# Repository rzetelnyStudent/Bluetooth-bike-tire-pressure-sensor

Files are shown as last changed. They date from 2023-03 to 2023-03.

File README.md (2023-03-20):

# Bluetooth-bike-tire-pressure-sensor
Bluetooth tire pressure sensor project. Measures pressure, tempreture and battery percentage.  Readings could be displayed with TPMSII android app from Play Store. Sensor is designed to be integrated with a valve and to bemounted inside a bike rim. 

This project was developed around nrf52832 microcontroller with Segger Embedded Studio and Nordic Semi SDK statement v17.1.0. Softdevice v7.2.0 (Bluetooth stack) from Nordic Semi was used.

For this project a custom PCB was designed in Altium Designer and a custom housing in TinkerCAD.

Functional description:
The sensor broadcasts pressure, temperature and battery data over BLE. The data format is compatible with the one used by BLE pressure sensor from aliexpress, like these:
https://youtu.be/v4x5Eum56oU

TPMSII Android app maps sensors using an ID coded in each sensor name and advertising data. Data format used by orginal sensors is described here:
https://github.com/ra6070/BLE-TPMS

My sensor is motion activated. It advertises data as long as the motion is detected. When motion stops for longer than 2 minutes, sensor stops advertising to preserve a battery. 

The sensor is powered using two CR927 batteries. The estimated battery lifetime is 3 years minimum assuming daily usage of 15 minutes.

Photo gallery:










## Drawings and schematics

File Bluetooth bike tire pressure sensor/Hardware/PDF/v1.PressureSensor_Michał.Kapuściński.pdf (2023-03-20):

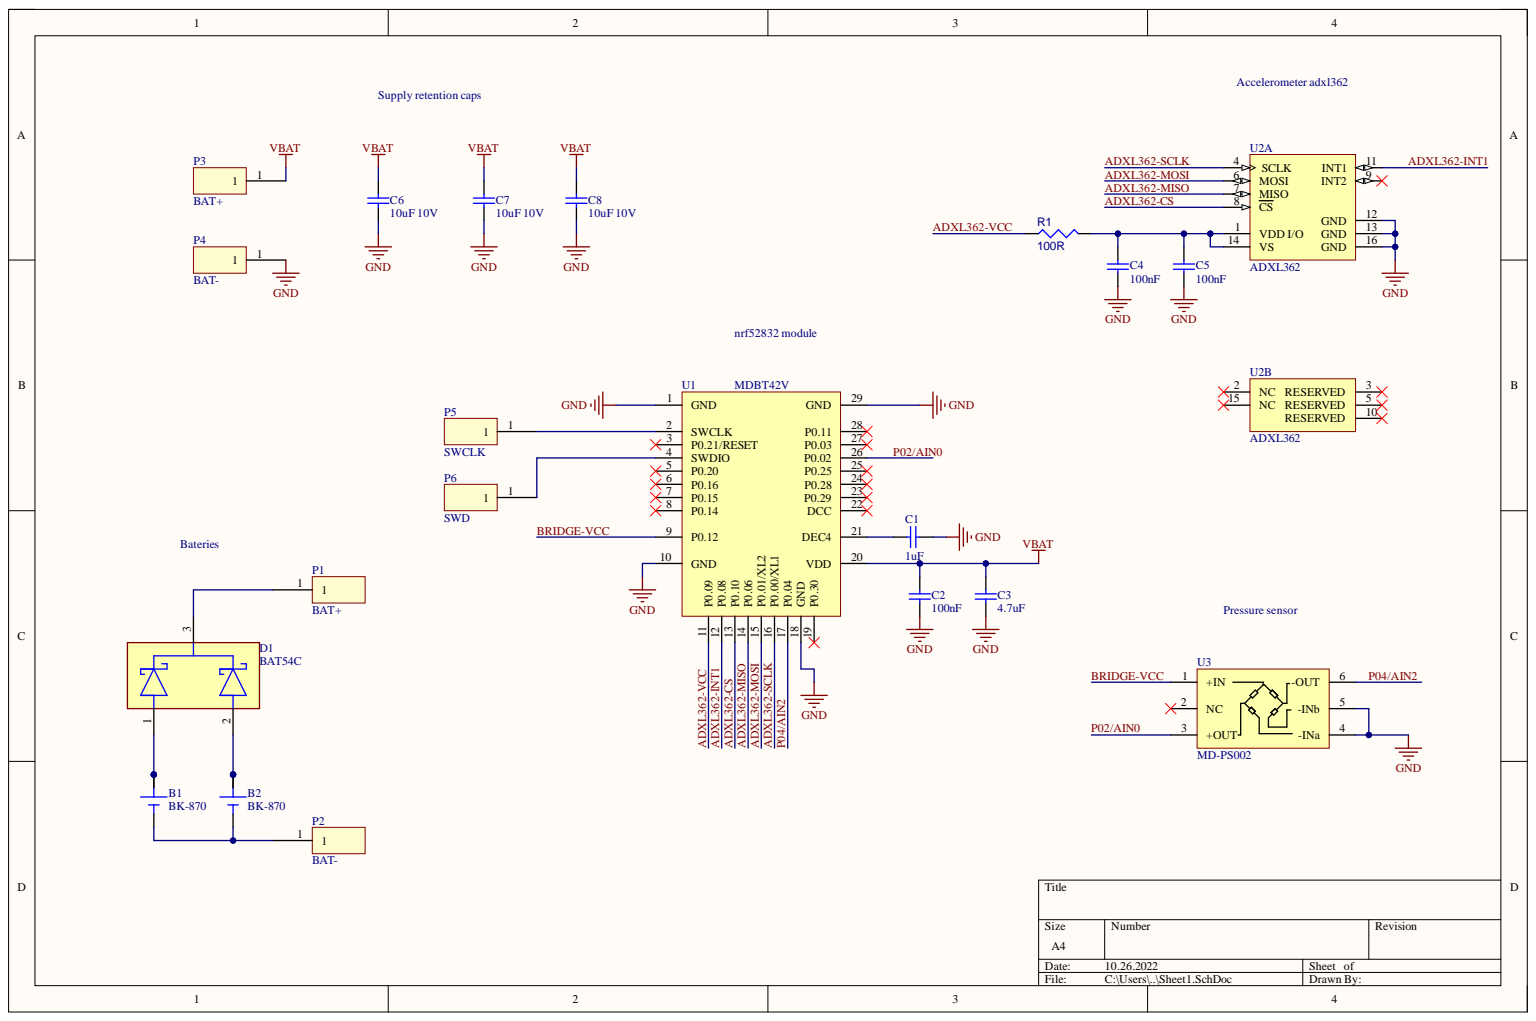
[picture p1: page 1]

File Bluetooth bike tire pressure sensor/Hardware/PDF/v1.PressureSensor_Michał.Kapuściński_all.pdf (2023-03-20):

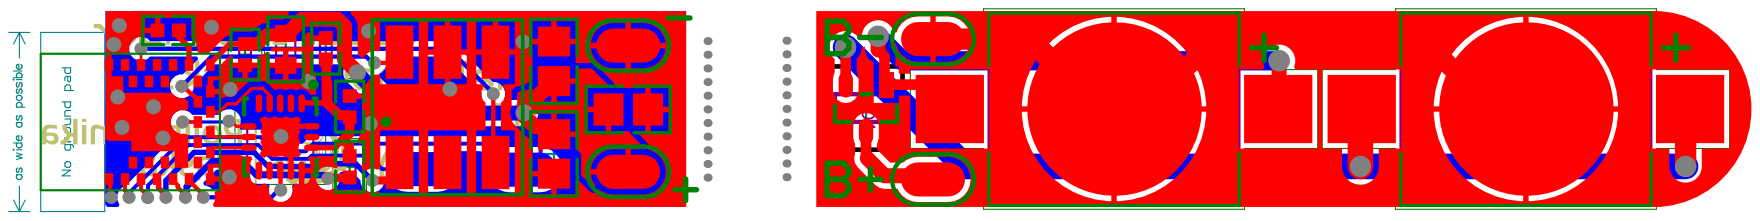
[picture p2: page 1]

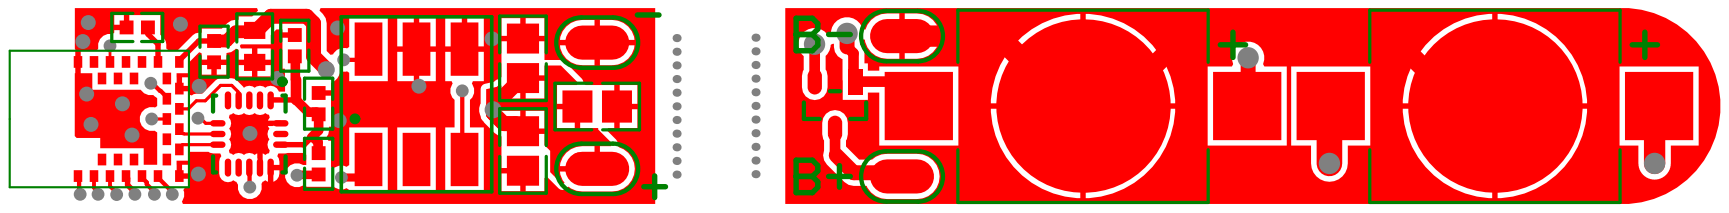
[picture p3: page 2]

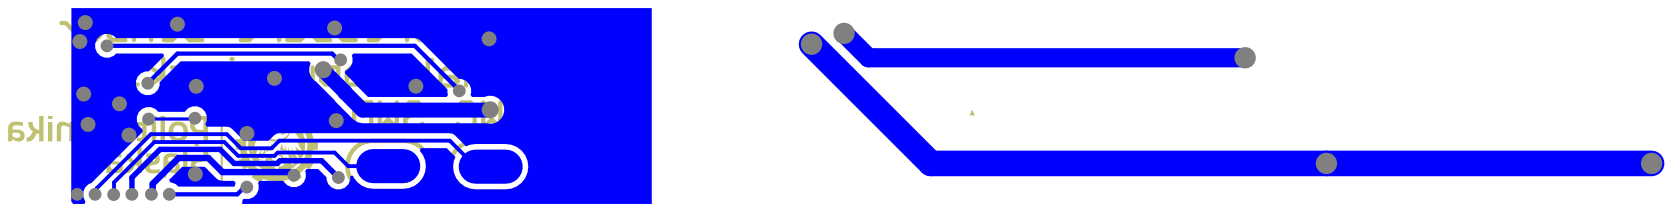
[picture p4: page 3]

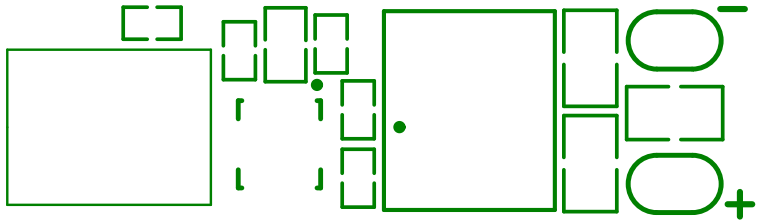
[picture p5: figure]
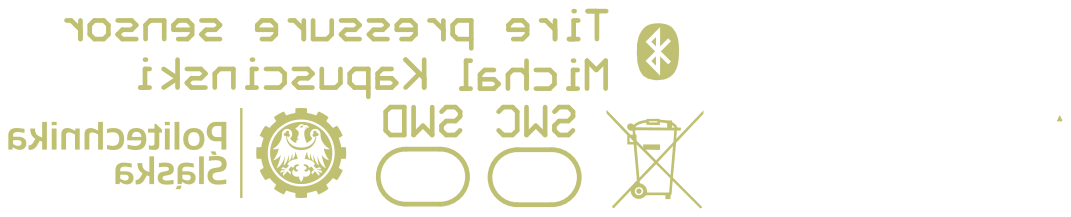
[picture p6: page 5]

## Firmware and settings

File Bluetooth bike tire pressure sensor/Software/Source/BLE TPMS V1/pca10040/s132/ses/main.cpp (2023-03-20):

/* Bluetooth tire pressure sensor project. Measures pressure, tempreture and battery percentage.
 * Readings could be displayed with TPMSII android app 
 */


#include "Sensor_id.h"
#include "Adxl362.h"
#include "my_advertising.h"
#include "my_config.h"
#include "ADC.h"
#include "mapper.h"
#include "measurments.h"
#include "sd_func_wrapper.h"



static bool timer_flag = false;
static uint8_t read_vbat_counter = 0;
APP_TIMER_DEF(m_app_timer_id);



/*
 * Main timer handler function that gets called every timer interval. I put all the application code in main().
 */
static void app_timer_handler(void *p_context)
{
    timer_flag = true;
    read_vbat_counter++;
}



/**@brief Function for starting timers.
 */
static void reading_timer_start(void)
{
    uint32_t err_code = app_timer_create(&m_app_timer_id, APP_TIMER_MODE_REPEATED, app_timer_handler); // Create timers
    APP_ERROR_CHECK(err_code);
    err_code = app_timer_start(m_app_timer_id, READ_TIMER_INTERVAL, NULL);     // start main timer
    APP_ERROR_CHECK(err_code);
}



/*
 * Function for initializing app timer library. Call in setup.
 */
static void appTimerInit(void)
{
    uint32_t err_code = app_timer_init();     // Initialize timer module
    APP_ERROR_CHECK(err_code);
}



// main function

int main(void)
{

    ///////////////////////////////////// SETUP /////////////////////////////////////////

    appTimerInit();
    powerManagementInit();

    bleStackInit();
    My_advertising advertiser;
    advertiser.addIdToAddress(cfg::SENSOR_ID);		// attach sensor id to advertising buffer

    ADC<cfg::BRIDGE_PIN, cfg::ADC_POSITIVE_INPUT, cfg::ADC_NEGATIVE_INPUT> adc;

    adc.calibrate();       // do initial calibration

    uint8_t bat_percentage = mapVbat(adc.analogReadVbat());		// bat percentage has to be "main global", since it is not read every loop iteration
    Measurments<cfg::PRESSURE_SENSITIVITY_KPA, cfg::TEMP_SENSITIVITY, cfg::TEMP_ADC_CALIBRATE>
        measurments(map(adc.analogReadPressure()), getTemperature(), bat_percentage);    // initialize measurments with real data

    advertiser.configureAdvertising(measurments.getPressure(), measurments.getTemperature(), measurments.getBatPercentage(), false);     // setup advertising

    reading_timer_start();     // start system main timer
    Adxl362<cfg::SS_PIN, cfg::MOSI_PIN, cfg::MISO_PIN, cfg::SCLK_PIN, cfg::ACC_VCC_PIN> adxl362;
    adxl362.setupMotionInterrupt<cfg::ACC_INT_PIN, cfg::ACTIVITY_THRESHOLD, cfg::INACTIVITY_THRESHOLD, cfg::INACTIVITY_TIME>();     // setup accelerometer for motion interrupt
    advertiser.startAdvertising();      // lastly: become visible (start advertising)

#ifdef ADXL362_DEBUG
	int i = 0;
#endif
    ///////////////////////////////////// LOOP /////////////////////////////////////////
    while (1)
    {

        if (timer_flag)       // do every second
        {

#ifdef ADXL362_DEBUG
			i++;
			printf("%d\n", adxl362.adxlReadRegister(0x08));
			printf("%d\n", i);
#endif

            timer_flag = false;      // reset timer flag
            int32_t temperature = getTemperature();		 // read temperature
            if (measurments.checkIfAdcNeedsCal(temperature))       // if the temperature changed sufficiently, calibrate ADC
            {
                adc.calibrate();
            }

            if (read_vbat_counter > cfg::READ_VBAT_INTERVAL)	   // battery percentage is read less often than pressure or temperature
            {
                read_vbat_counter = 0;      // reset Vbat reading counter
                bat_percentage = mapVbat(adc.analogReadVbat());      // read Vbat (Vcc) and map it to %s
            }

#ifdef CALIBRATION
			
			// if calibration is enabled, raw readings (without any mappings or checkings are advertised)
			uint32_t pressure = map(adc.analogReadPressure());
            //printf("Pressure: %d\n", pressure);

            advertiser.updateAdvertising(adc.analogReadPressure(), temperature, bat_percentage, false);

#else	// advertise converted and filtered readings
			
			// check if measured values changed since the previous readings. It is done to prevent displaying noisy readings
            if (measurments.checkForChanges(map(adc.analogReadPressure()), temperature, bat_percentage))
            {
				// if they changed, update transmitted data
                advertiser.updateAdvertising(measurments.getPressure(), measurments.getTemperature(), measurments.getBatPercentage(), false);
            }


#endif // CALIBRATION

#ifndef CALIBRATION
            if (0 == nrf_gpio_pin_read(cfg::ACC_INT_PIN))	 // check if there's no motion detected for 2 mins (accelerometer signals an inactivity interrupt)
            {
                sleepSysOffEnter();     // go to system off sleep mode (the wake up source is accelerometer pin)
            }
#endif // CALIBRATION
        }

        idle_state_handle();       // go to system ON sleep mode (until next timer interrupt)
    }
}

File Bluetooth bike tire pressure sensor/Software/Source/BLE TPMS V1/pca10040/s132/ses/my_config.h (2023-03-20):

#ifndef MY_CONFIG_H
#define MY_CONFIG_H

#include "Sensor_id.h"
#include "my_utility.h"
#include "nrf_sdh_ble.h"

namespace cfg
{


/////////////////////////////////////////////// SENSOR ID //////////////////////////////////////////////

constexpr const Sensor_id SENSOR_ID {{0x00, 0x00, 0x04}, Which_wheel::REAR_RIGHT};
// ^ sensor ID will be displayed in: Bluetooth name, Bluetooth address, manufacturer data in advertising packet.
// The android app ("TPMSII") does only care about the 3-byte ID coded in manufacturer data, when it identifies a sensor.

////////////////////////////////////////////// CALIBRATION ////////////////////////////////////////////////

//#define CALIBRATION	   // when defined, sensor prints raw pressure readings, without any checks or mappings


////////////////////////////////////////////// ADVERTISING DATA ///////////////////////////////////////////l

const uint16_t ADV_DATA_L = 27;
const uint16_t SCAN_DATA_L = 14;


// The advertising data packet contains: device ID, pressure, temperature, battery percentage
const uint8_t MY_ADV_DATA[ADV_DATA_L] = {

    0x02, BLE_GAP_AD_TYPE_FLAGS, BLE_GAP_ADV_FLAGS_LE_ONLY_GENERAL_DISC_MODE,     // original sensor has 0x05 here (LE_LIMITED_DISC_MODE),    
	// so it advertises only for <180s. My sensor advertises as long as the movement is detected. The android app doesn't care about this byte.
    0x03, BLE_GAP_AD_TYPE_16BIT_SERVICE_UUID_COMPLETE, 0xB0, 0xFB,    // original sensor contains a service 0xfbb0. Weird, since it is non connetable
	// (one cannot discover its services) + 0xfbb0 is not a assigned bluetooth UUID (16-bit UUIDs are reserved).
    0x13, BLE_GAP_AD_TYPE_MANUFACTURER_SPECIFIC_DATA, 0x00, 0x01,    // manufacturer TOMTOM international. Even more weird, since the original sensors are sold no - branded
	SENSOR_ID.which_wheel + 0x80, 0xEA, 0xCA, SENSOR_ID.id_hex[0], SENSOR_ID.id_hex[1], SENSOR_ID.id_hex[2], 
	0x00, 0x00, 0x00, 0x00,     // pressure (little endian) in kPa * 1000
	0x00, 0x0D, 0x00, 0x00,		// temperature (little endian) in *C * 100
	0x02,						// battery percentage
    0x00,						// leak flag (when set to true, app says that tire leaks)
};


const uint8_t MY_SCAN_RESP_DATA[SCAN_DATA_L] =
    {
        0x0D, BLE_GAP_AD_TYPE_COMPLETE_LOCAL_NAME, char('T'), char('P'), char('M'), char('S'), 
		lowerHalfByteToAscii<SENSOR_ID.which_wheel + 1>(), char('_'), 
		upperHalfByteToAscii<SENSOR_ID.id_hex[0]>(), lowerHalfByteToAscii<SENSOR_ID.id_hex[0]>(), 
		upperHalfByteToAscii<SENSOR_ID.id_hex[1]>(), lowerHalfByteToAscii<SENSOR_ID.id_hex[1]>(), 
		upperHalfByteToAscii<SENSOR_ID.id_hex[2]>(), lowerHalfByteToAscii<SENSOR_ID.id_hex[2]>()
	};




////////////////////////////////////////////////// PINS //////////////////////////////////////////////////////////////

const uint32_t SS_PIN = 8;   // MDBT42V pin 12   // 28
const uint32_t MISO_PIN = 6; // MDBT42V pin 14   // 29
const uint32_t MOSI_PIN = 1; 
const uint32_t SCLK_PIN = 0; 
const uint32_t ACC_VCC_PIN = 14;
const uint32_t ACC_INT_PIN = 12;
const uint32_t ADC_POSITIVE_INPUT = SAADC_CH_PSELP_PSELP_AnalogInput0;  //P28    //A0  // 2
const uint32_t ADC_NEGATIVE_INPUT = SAADC_CH_PSELP_PSELP_AnalogInput2;  // P29    // A1 // 3     A2 - 4
const uint32_t BRIDGE_PIN = 16;



/////////////////////////////////////////// ACCELEROMETER PARAMETERS //////////////////////////////////////////////////

const uint8_t ACTIVITY_THRESHOLD = 170;   // 160mg
const uint8_t INACTIVITY_THRESHOLD = 160;  // 80mg
const uint16_t INACTIVITY_TIME = 120;      // 120s



/////////////////////////////////////////// PRESSURE CALIBRATION PARAMETERS ///////////////////////////////////////////

const float A_COEFFICIENT = 2.1333;
const float B_COEFFICIENT = -81.597;



/////////////////////////////////////////////////////// SENSITIVITY ///////////////////////////////////////////////////

const int16_t PRESSURE_SENSITIVITY_KPA = 6;     // 60 mBar
const int32_t TEMP_SENSITIVITY = 600;     // 6 *C



///////////////////////////////////////////////// ADC CALIBRATION //////////////////////////////////////////////////////

const int32_t TEMP_ADC_CALIBRATE = 750;     // = 7.5*C


///////////////////////////////////////////////// TIME INTERVALS ///////////////////////////////////////////////////////


#define READ_INTERVAL 1000      // defines how often the sensor should read, advertise and display pressure
#define READ_TIMER_INTERVAL APP_TIMER_TICKS(READ_INTERVAL)     // converts read interval to app timer ticks
#define ADVERTISING_INTERVAL MSEC_TO_UNITS(READ_INTERVAL, UNIT_0_625_MS)     // converts read interval to adverting interval
const uint8_t READ_VBAT_INTERVAL = 10;      // Vbat gets read every READ_INTERVAL * READ_VBAT_INTERVAL seconds

};


#endif
